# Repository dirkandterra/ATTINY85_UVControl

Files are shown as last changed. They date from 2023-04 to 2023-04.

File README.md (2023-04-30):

# ATTINY85_UVControl
Controlling UV LED Strip with ATTINY85 and scrap printer part

The attached code is to run on an ATTINY85, but there is a compiler directive that will allow a build to nano for testing (to have serial)

The ATTINY is programmed using Arduino as ISP.  Hook the wires up accordingly:

Arduino====>Attiny====>Attiny85   
D10=======>RESET======>PIN1   
D11=======>MOS======>PIN5   
D12=======>MISO======>PIN6    
D13=======>SCK======>PIN7   
5V========>VCC======>PIN8 (I just power on the board instead of hooking this up)    
GND======>GND=====>PIN4   
(MOSI,MISO,RESET. 5V for programming is supplied from the device, not the programmer.)

**IMPORTANT**
You will also need a fairly large cap (100-1000uF) across the RST of the Arduino pin (+ side if cap is polarized) and GND.  This is to keep the Nano from resetting itself when programming.  You will also have to upload the Arduino as ISP image to the nano first for it to function properly.

Add "https://raw.githubusercontent.com/damellis/attiny/ide-1.6.x-boards-manager/package_damellis_attiny_index.json" to board manager URLs

Board Settings:
Device: ATTINY25/45/85
Internal Clk: 1MHZ
Processor: ATTINY85
Programmer: Arduino as ISP

Program Description:    
The top button starts the UV timer and the side button toggles between the "set time" mode and the "UV light" mode.   
In the "set time mode", each top button press adds 30 sec to the time.  The top button led flashes once for every minute    
and a quick blip if a 30 sec addition is made.  Default is seven minutes.

For LEDs: (AMARS Black LED Lights Strip for Decoration, DC12V 24W 5050 SMD 2M/6.6FT 390nm-405nm), 54 LEDs were used and draw 500mA

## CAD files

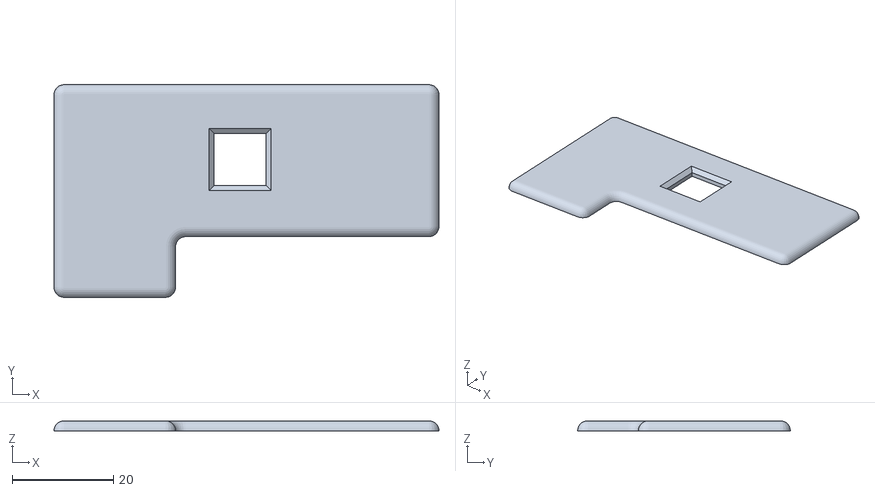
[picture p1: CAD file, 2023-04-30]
CAD/STL Files/UV_Box-Lid.stl
76.0 x 42.0 x 2.00

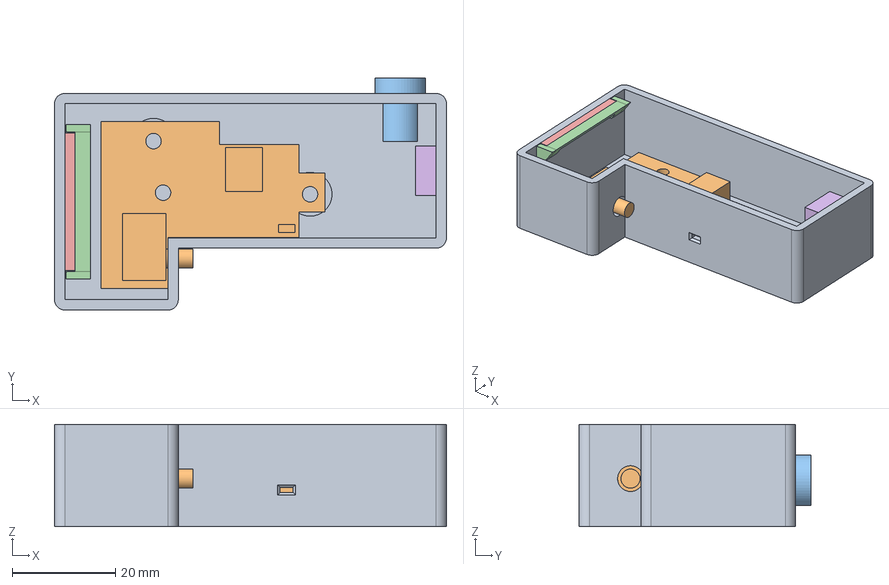
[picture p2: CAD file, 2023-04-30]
CAD/UV_Box.FCStd
76.0 x 45.0 x 19.8 mm
BoardMockup
PowerMockup
Latch_Hook
Latch
LatchScrew

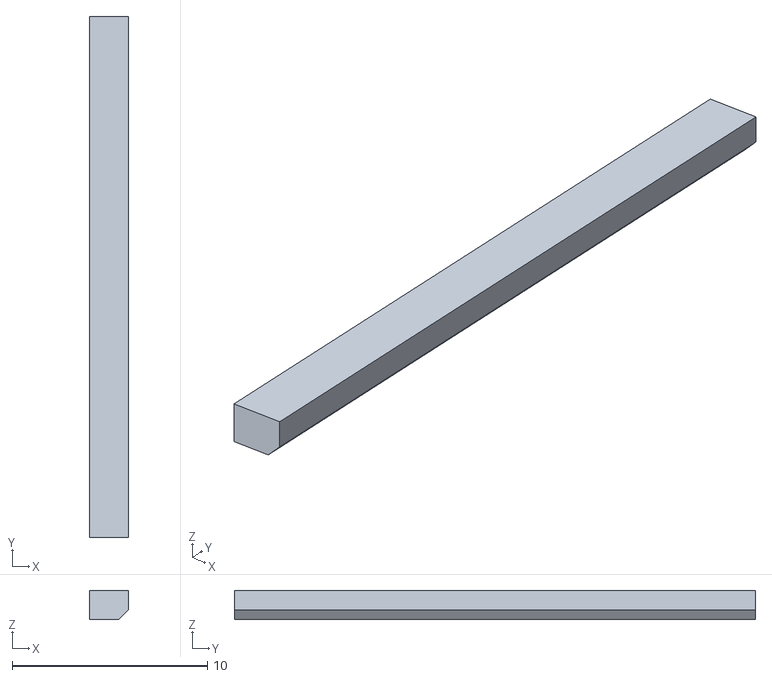
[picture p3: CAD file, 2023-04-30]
CAD/STL Files/UV_Box-Latch.stl
2.00 x 26.7 x 1.50

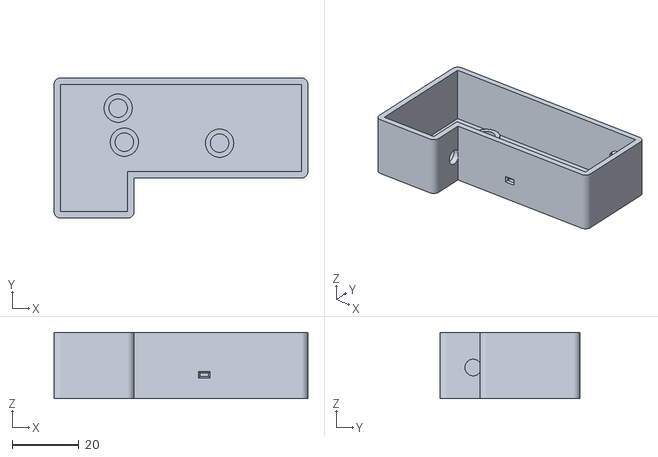
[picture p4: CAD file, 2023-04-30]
CAD/STL Files/UV_Box-Box.stl
76.0 x 42.0 x 19.8

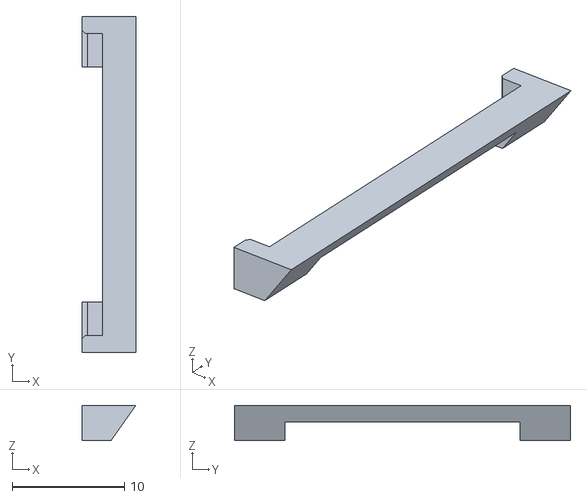
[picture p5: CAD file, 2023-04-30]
CAD/STL Files/UV_Box-Latch_Hook.stl
4.80 x 30.0 x 3.15

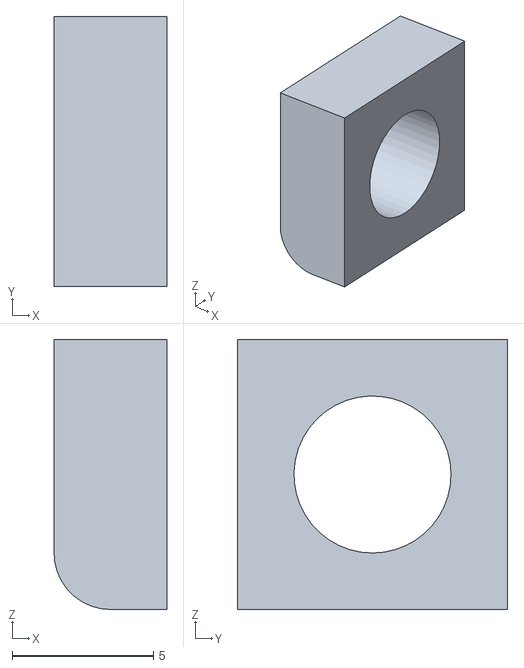
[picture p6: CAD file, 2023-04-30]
CAD/STL Files/UV_Box-LatchScrew.stl
4.00 x 9.56 x 9.56

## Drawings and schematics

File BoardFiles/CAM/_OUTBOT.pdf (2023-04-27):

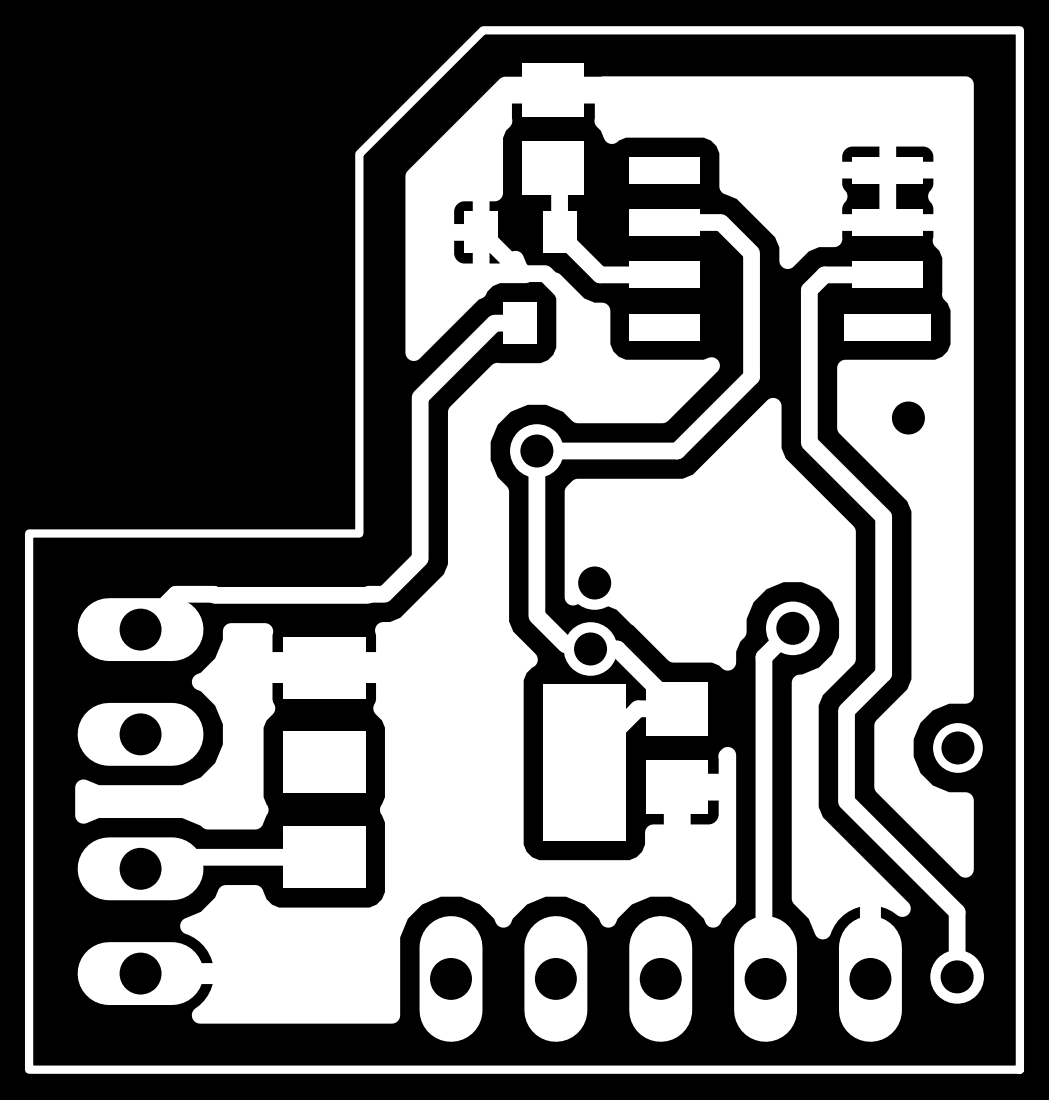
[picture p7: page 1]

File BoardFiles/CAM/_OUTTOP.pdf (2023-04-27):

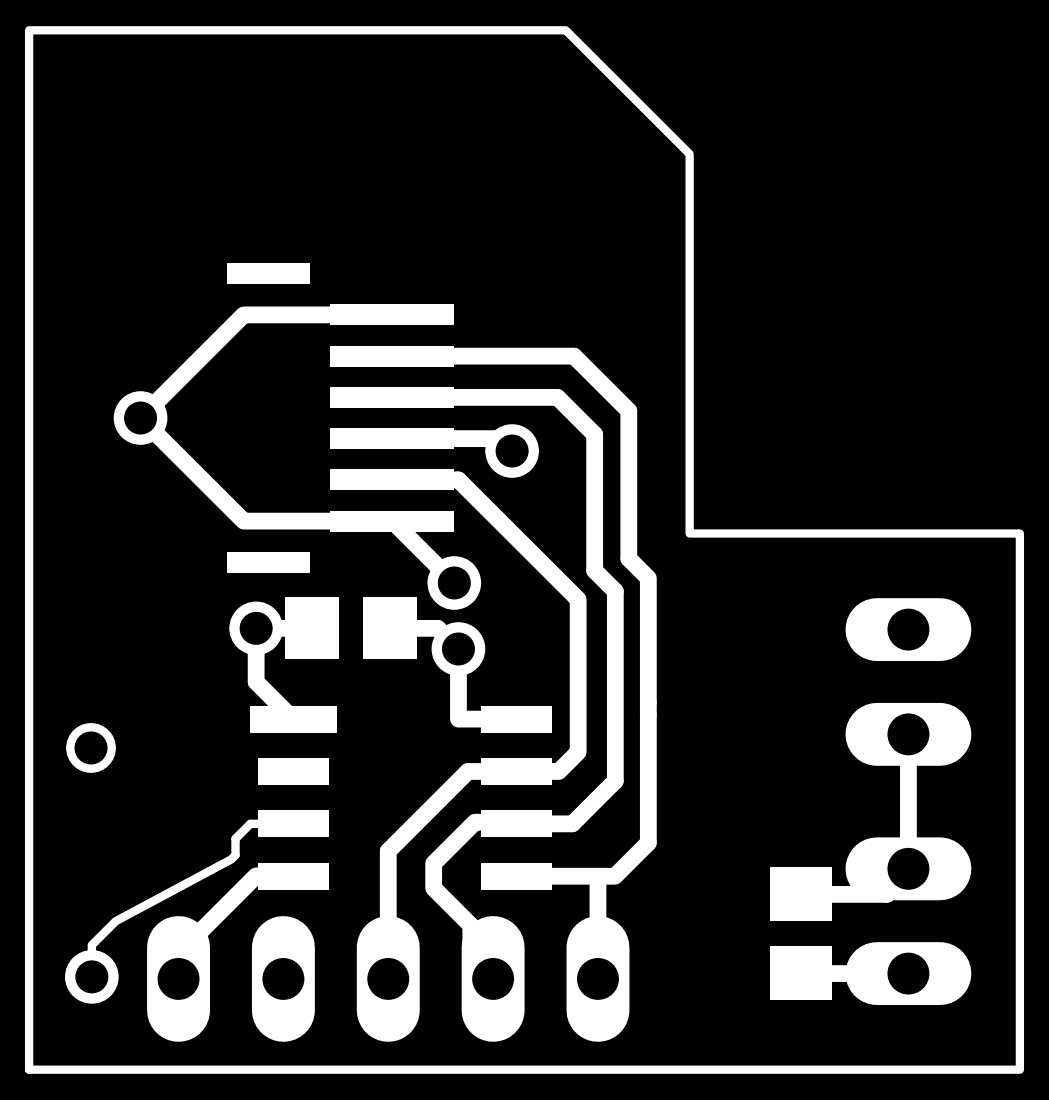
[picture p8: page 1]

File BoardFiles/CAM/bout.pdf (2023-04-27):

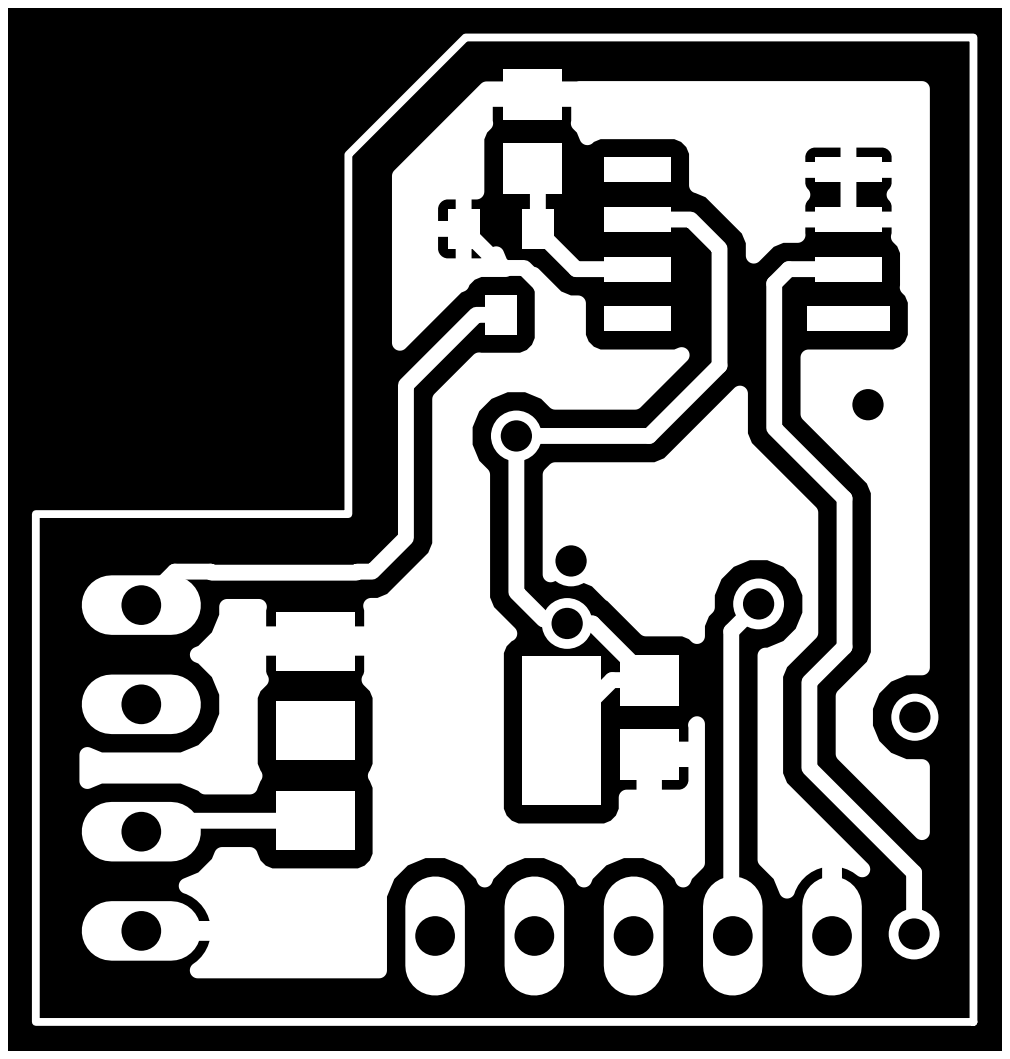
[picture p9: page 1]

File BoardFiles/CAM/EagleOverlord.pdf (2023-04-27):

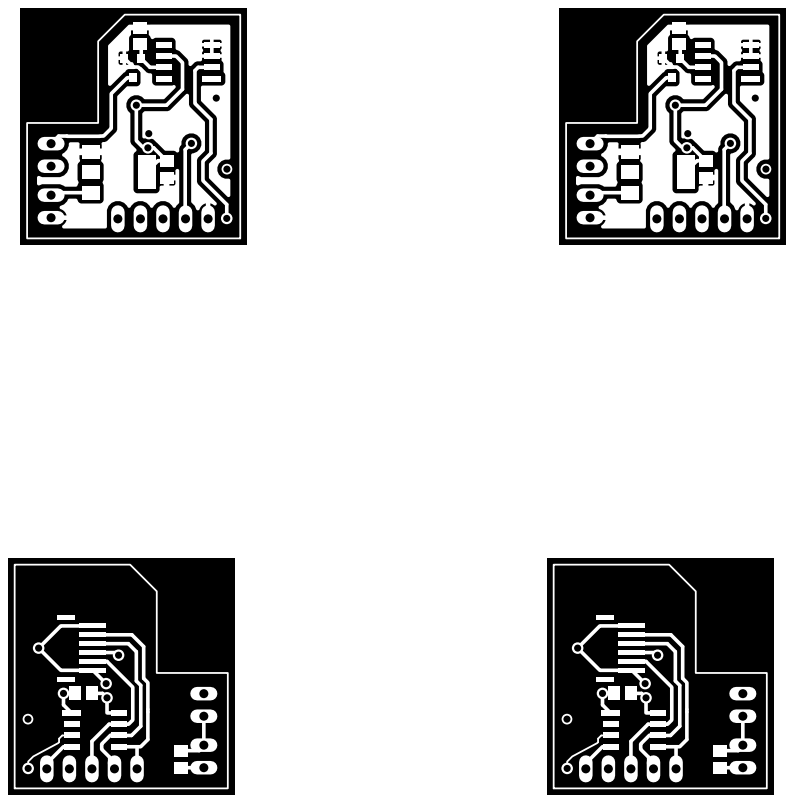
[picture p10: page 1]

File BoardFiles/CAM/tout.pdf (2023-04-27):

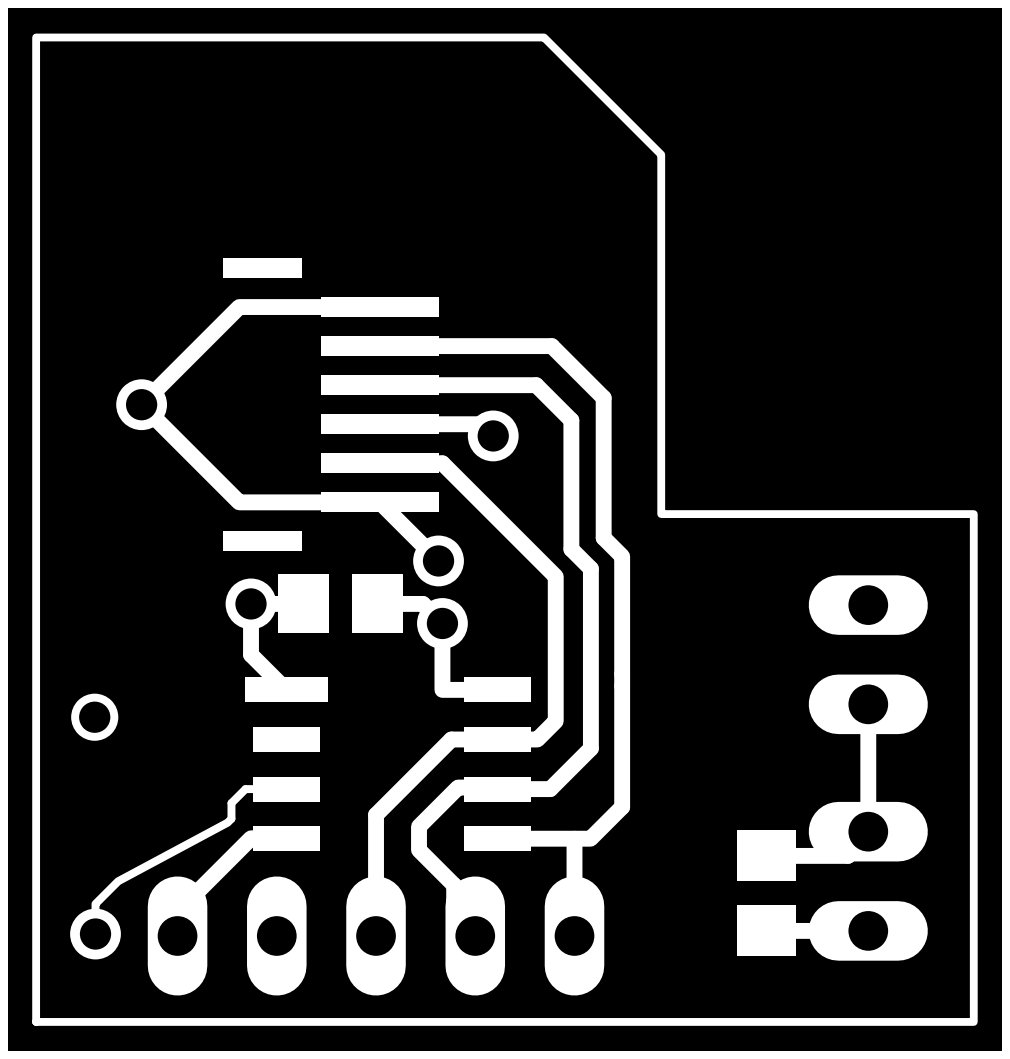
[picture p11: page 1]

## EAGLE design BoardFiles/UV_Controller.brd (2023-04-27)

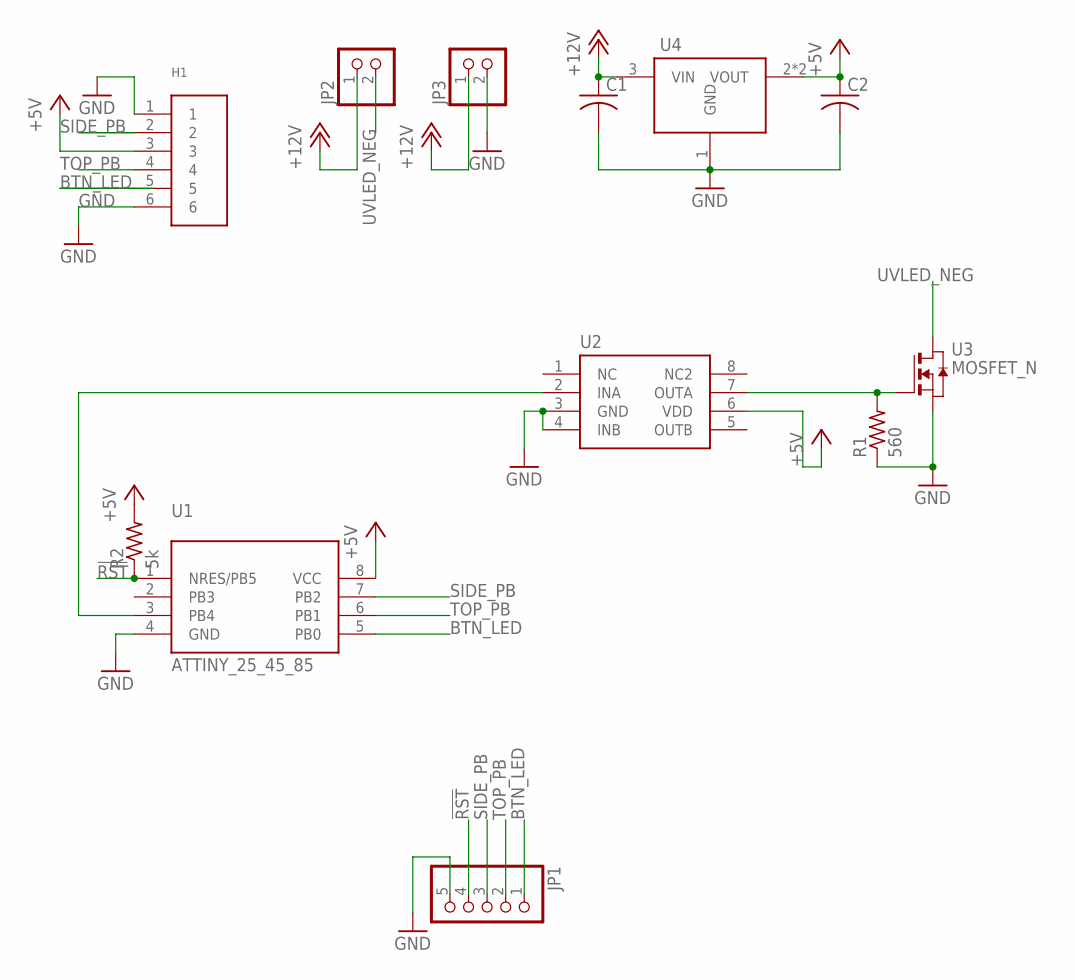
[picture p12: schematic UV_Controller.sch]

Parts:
C1, C2: C-USC0805; C0805
H1: 6PIN_RIBBON_CONN_1MM; 6PIN_SMD_CONN_1MM
JP1: PINHD-1X5; 1X05
JP2, JP3: PINHD-1X2; 1X02
R1: 560; R0805
R2: 5k; R0805
U1: ATTINY_25_45_85; SOIC-8
U2: TC427; SOIC-8
U3: MOSFET_N; SOT-23
U4: NCP1117ST50T3G; SOT223

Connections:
!RST: JP1.4, R2.1, U1.1 (NRES/PB5)
+5V: C2.1, H1.3, R2.2, U1.8 (VCC), U2.6 (VDD), U4.2 (VOUT), U4.4 (VOUT)
+12V: C1.1, JP2.1, JP3.1, U4.3 (VIN)
BTN_LED: H1.5, JP1.1, U1.5 (PB0)
GND: C1.2, C2.2, H1.1, H1.6, JP1.5, JP3.2, R1.1, U1.4 (GND), U2.3 (GND), U2.4 (INB), U3.3 (S), U4.1 (GND)
unnamed: U1.3 (PB4), U2.2 (INA)
unnamed: R1.2, U2.7 (OUTA), U3.2 (G)
SIDE_PB: H1.2, JP1.3, U1.7 (PB2)
TOP_PB: H1.4, JP1.2, U1.6 (PB1)
UVLED_NEG: JP2.2, U3.1 (D)

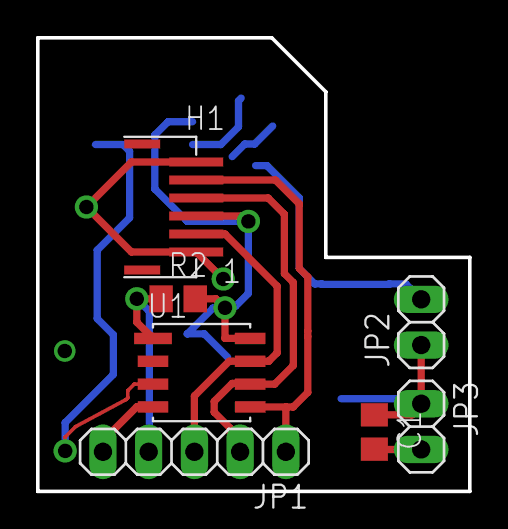
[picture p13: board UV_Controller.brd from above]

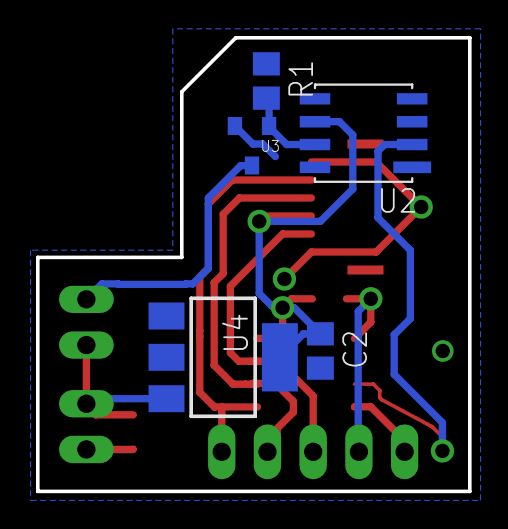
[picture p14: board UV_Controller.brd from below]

Board: 2 copper layers, 24.0 x 25.2 mm, 12 parts (5 on the bottom side), 10 nets.

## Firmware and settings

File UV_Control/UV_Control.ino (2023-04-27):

#define DEBOUNCE 500
#define FLASHMS 250
#define TRUE 1
#define FALSE 0
//#define NANO
#ifdef NANO
  const int btnled = 13; //0
#else
  const int btnled = 0; //0
#endif
uint32_t cycleMillis=0;
bool ProgramMode=0;
typedef struct btn_S{
  int pinNum;
  uint32_t dbTimer;
  bool triggered;
}btn_T;

uint32_t ledFlasherTimer=0;
int ledFlasherState=0;
int uvMinutes=0;
int uvHalfMin=0;

typedef struct uv_S{
  int pinNum;
  bool OnCmd;
  uint32_t On_Timer;
  uint32_t uvSecSetpoint;
}uv_T;

btn_T TopBtn;
btn_T SideBtn;
uv_T UVLight;

// the setup routine runs once when you press reset:
void setup() {
  //
  #ifdef NANO
    Serial.begin(115200);
  #endif
  UVLight.pinNum=4;//4;
  TopBtn.pinNum=1;//1;
  SideBtn.pinNum=2;//2;
  UVLight.OnCmd=FALSE;
  UVLight.uvSecSetpoint=420000;  //7 Min
  UVLight.On_Timer=0;
  TopBtn.dbTimer=0;
  TopBtn.triggered=0;
  SideBtn.dbTimer=0;
  SideBtn.triggered=0;
  // initialize the digital pin as an output.
  pinMode(btnled, OUTPUT);
  pinMode(UVLight.pinNum, OUTPUT);
  pinMode(SideBtn.pinNum, INPUT_PULLUP);
  pinMode(TopBtn.pinNum, INPUT_PULLUP);
  digitalWrite(UVLight.pinNum,  LOW); // turn the UV Off (HIGH is the voltage level)   
  digitalWrite(btnled,  HIGH); // turn the LED on (HIGH is the voltage level)  
  delay(1000);
}

void btnTriggered(btn_T *btn){
  bool currentRead=!digitalRead(btn->pinNum);  //Inverted because gnded is active
  if(cycleMillis>btn->dbTimer){
    if(currentRead){
      btn->dbTimer=cycleMillis+DEBOUNCE; //Lockout for debounce setpoint
      btn->triggered=TRUE;
      #ifdef NANO
      Serial.print("Triggered Until: ");
      Serial.print(btn->dbTimer);
      Serial.print("- ");
      Serial.println(currentRead);
      #endif
    }
  }
}

void statusFlashHandler(void){
    if(cycleMillis>=ledFlasherTimer){
      //keep led off before restarting sequence
      if((uvMinutes==(ledFlasherState/2)) && uvHalfMin){
        digitalWrite(btnled, LOW); // turn the LED on (HIGH is the voltage level)
        ledFlasherTimer=cycleMillis+FLASHMS/2;
        ledFlasherState+=2; 
      }else if(uvMinutes>=((ledFlasherState/2)+1)){
        if(ledFlasherState%2==0){
           digitalWrite(btnled, LOW); // turn the LED on (HIGH is the voltage level)
        }else{
           digitalWrite(btnled,  HIGH); // turn the LED on (HIGH is the voltage level)
        }
        ledFlasherTimer=cycleMillis+FLASHMS;
        ledFlasherState++;
      }else{
        digitalWrite(btnled,  HIGH); // turn the LED on (HIGH is the voltage level)
        if((ledFlasherState/2)>(uvMinutes+2)){
          ledFlasherState=0;
        }else{
          ledFlasherState++;
        }
        ledFlasherTimer=cycleMillis+FLASHMS;
      }
    }
}

// the loop routine runs over and over again forever
void loop() {
  static bool oldUVCmd=FALSE;
  uvMinutes=UVLight.uvSecSetpoint/60000;
  uvHalfMin=UVLight.uvSecSetpoint%60000;
  
  cycleMillis=millis();
  btnTriggered(&SideBtn);  //Check btn status
  btnTriggered(&TopBtn);   //Check btn status


  if(SideBtn.triggered){
    SideBtn.triggered=FALSE;
    ProgramMode=!ProgramMode;
    //Serial.print(ProgramMode);
    //Serial.println( " : ProgMode");
    digitalWrite(btnled,  HIGH); // start the mode change with the BTN LED off
    ledFlasherState=0;
  }

  //Programming mode
  if(ProgramMode){
    UVLight.OnCmd=FALSE;
    if(TopBtn.triggered){
      TopBtn.triggered=FALSE;
      UVLight.uvSecSetpoint+=30000;
      //Serial.print(UVLight.uvSecSetpoint);
      //Serial.println( " : Setpoint");
      uvMinutes=UVLight.uvSecSetpoint/60000;
      uvHalfMin=UVLight.uvSecSetpoint%60000;
      //Serial.print(uvMinutes);
      //Serial.print(" : ");
      //Serial.print(uvHalfMin);
      //Serial.println("");
      if(UVLight.uvSecSetpoint>600000){
        UVLight.uvSecSetpoint=30000;  //If greater than 10 min, start over at 1/2 minute
      }
      ledFlasherState=0;  //start indication sequence over again
    }
    statusFlashHandler();
  //Normal Run Mode
  }else{
      //UV Timer Timed out?
      if((UVLight.On_Timer<=cycleMillis) && UVLight.OnCmd){
        UVLight.OnCmd=FALSE;
      }
      //UV start/stop?
      if(TopBtn.triggered){
        TopBtn.triggered=FALSE;
        UVLight.OnCmd=!UVLight.OnCmd;
      }
      
      if(UVLight.OnCmd != oldUVCmd){
        if(UVLight.OnCmd){
          UVLight.On_Timer=cycleMillis + UVLight.uvSecSetpoint; //420000; 
          digitalWrite(UVLight.pinNum, HIGH); // turn the LED on (HIGH is the voltage level)
          digitalWrite(btnled, LOW); // turn the LED on (HIGH is the voltage level) 
        }else{
          UVLight.On_Timer=cycleMillis;
          digitalWrite(btnled,  HIGH); // turn the LED on (HIGH is the voltage level)
          digitalWrite(UVLight.pinNum,  LOW); // turn the LED on (HIGH is the voltage level)   
        }
        #ifdef NANO
          Serial.print(UVLight.OnCmd);
          Serial.print("<<--");
          Serial.print(oldUVCmd);
          Serial.println(""); 
        #endif 
      }
      oldUVCmd=UVLight.OnCmd;
  }  
}

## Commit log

2023-04-27 Initial commit
    yes
    [UV_Controller.brd, UV_Controller.sch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]
2023-04-30 Update README.md
    Wiring info
2023-04-30 Add files via upload
    Added Box 3D Files
    [UV_Box-Box.stl, UV_Box-Latch.stl, UV_Box-LatchScrew.stl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]
